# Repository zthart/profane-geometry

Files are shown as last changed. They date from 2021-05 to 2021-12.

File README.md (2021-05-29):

# Profane Geometry

I'm making (attempting) a Eurorack Module.

## What is it?

It's gonna be an oscillator builder/mixer based on a digitally-controlled Triangle Core VCO I found in a [research paper](https://www.researchgate.net/figure/Voltage-controlled-triangle-signal-generator-circuit_fig1_276412272).
It will be controlled by the atsamd21 or atsamd11 (depending on what I end up needing and what is in stock) family of MCUs and have firmware written in Rust!

## Dang aren't you like a web developer?

Yes.
I've only barely figured out the building blocks of some of this stuff, and my knowledge extends to pretty much exactly what I've built so far.
There are almost certainly issues with it.
The OSHW community is great though and people who publish the source/schematics for their Eurorack modules have been a massive, _massive_ help.

## Dang isn't there like a global parts shortage.

Yes.
It's annoying.

## Dang can I make one of these?

Sure.
Probably it will be bad.

## What's in this repo?

- The `./profane_geometry` directory houses the KiCad project for the oscillator board
- The `./profane_geometry_jackboard` directory houses the KiCad project for the jackboard
- The `./firmare` directory contains some testing firmare designed for the first iteration of the jackboard, which allows for an Adafruit Feather M0 to be attached with breadboard-pitch pin sockets

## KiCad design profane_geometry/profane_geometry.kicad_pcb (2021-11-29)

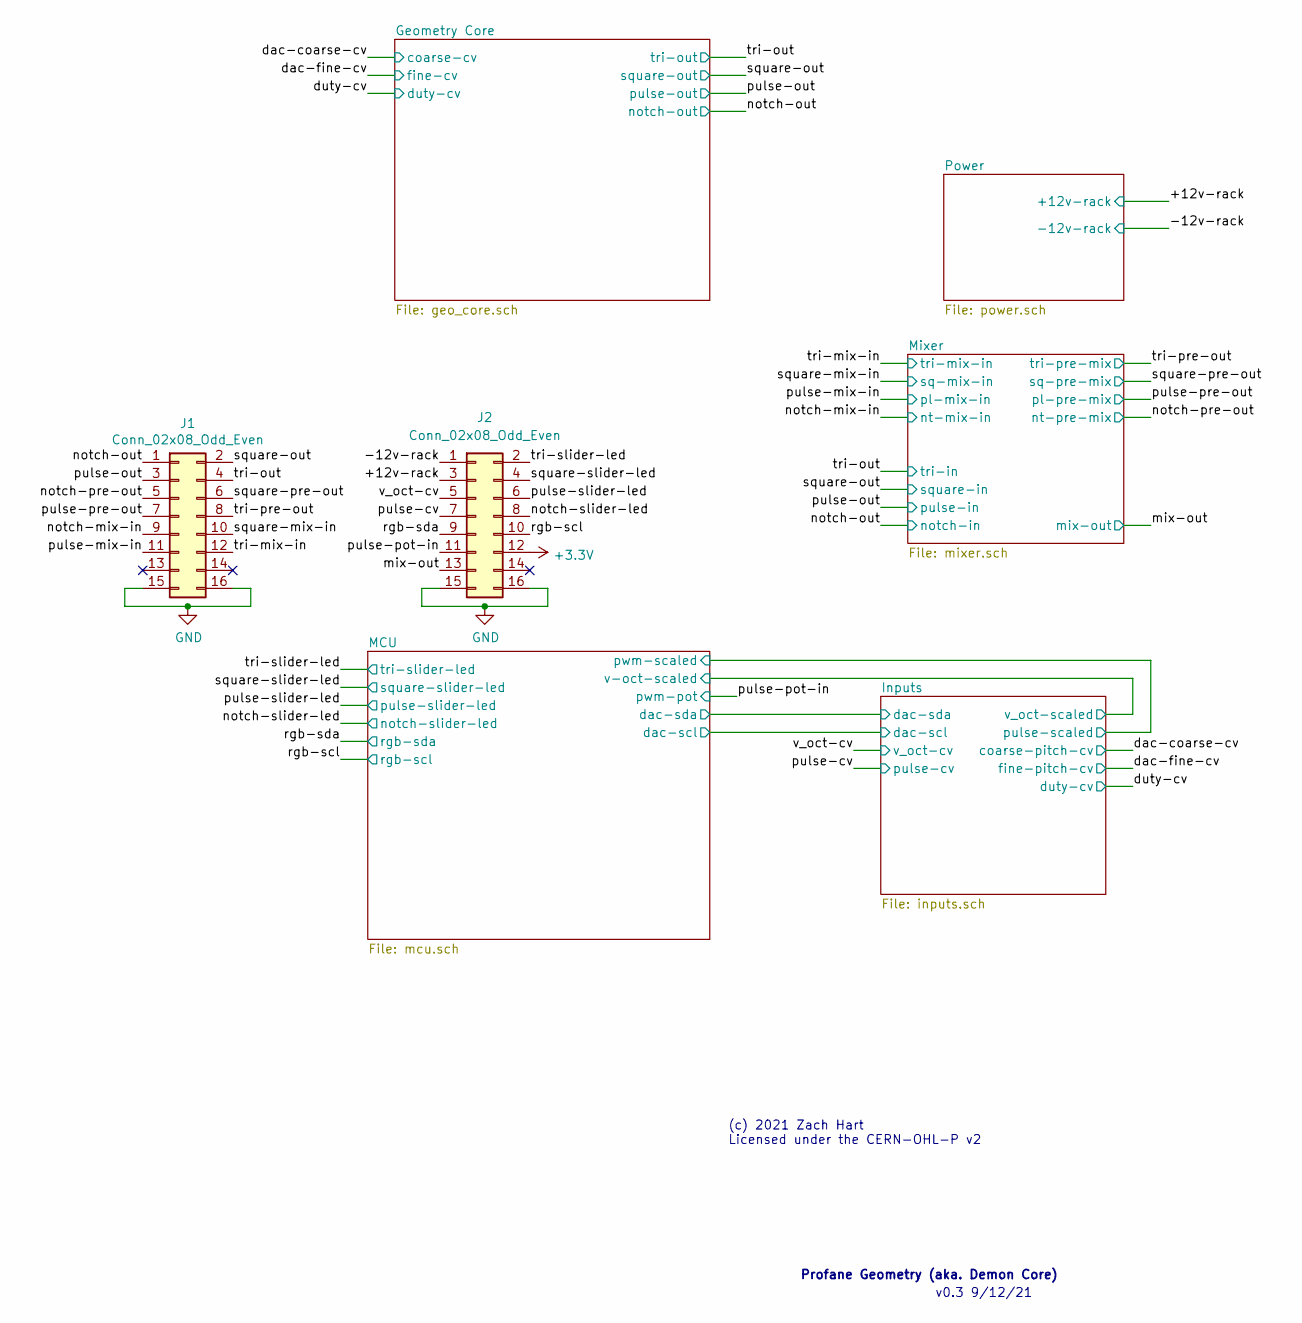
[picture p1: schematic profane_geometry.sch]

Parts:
J1, J2: Conn_02x08_Odd_Even; PinHeader_2x08_P2.54mm_Vertical

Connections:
/+12v-rack: J2.3; also elsewhere on the board
/-12v-rack: J2.1; also elsewhere on the board
/mix-out: J2.13; also elsewhere on the board
/notch-mix-in: J1.9; also elsewhere on the board
/notch-out: J1.1; also elsewhere on the board
/notch-pre-out: J1.5; also elsewhere on the board
/notch-slider-led: J2.8; also elsewhere on the board
/pulse-cv: J2.7; also elsewhere on the board
/pulse-mix-in: J1.11; also elsewhere on the board
/pulse-out: J1.3; also elsewhere on the board
/pulse-pot-in: J2.11; also elsewhere on the board
/pulse-pre-out: J1.7; also elsewhere on the board
/pulse-slider-led: J2.6; also elsewhere on the board
/rgb-scl: J2.10; also elsewhere on the board
/rgb-sda: J2.9; also elsewhere on the board
/square-mix-in: J1.10; also elsewhere on the board
/square-out: J1.2; also elsewhere on the board
/square-pre-out: J1.6; also elsewhere on the board
/square-slider-led: J2.4; also elsewhere on the board
/tri-mix-in: J1.12; also elsewhere on the board
/tri-out: J1.4; also elsewhere on the board
/tri-pre-out: J1.8; also elsewhere on the board
/tri-slider-led: J2.2; also elsewhere on the board
/v_oct-cv: J2.5; also elsewhere on the board
GND: J1.15, J1.16, J2.15, J2.16; also elsewhere on the board

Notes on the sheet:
Profane Geometry (aka. Demon Core)
(c) 2021 Zach Hart Licensed under the CERN-OHL-P v2
v0.3 9/12/21

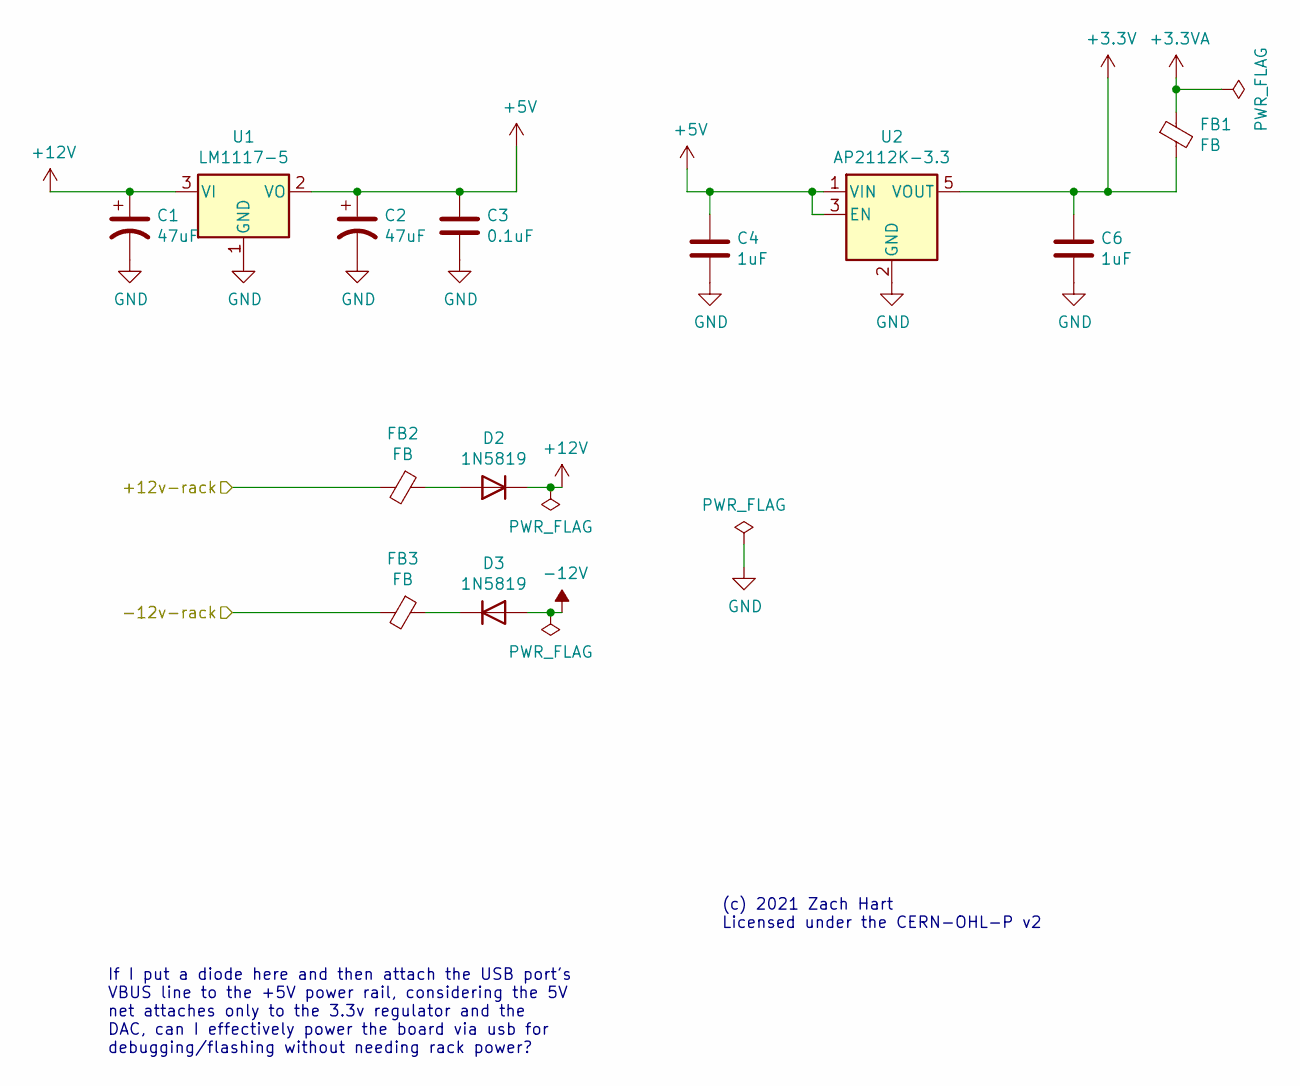
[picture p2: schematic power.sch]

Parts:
C1, C2: 47uF; CP_Elec_6.3x5.7; MFG Part No. 35SVPK47M
C3: 0.1uF; C_0805_2012Metric; MFG Part No. 08055C104KAT4A
C4, C6: 1uF; C_0805_2012Metric; MFG Part No. 0805DC105KAT2A
D2, D3: 1N5819; D_SOD-123; MFG Part No. 1N5819HWQ-7-F
FB1, FB2, FB3: FB; L_1210_3225Metric_Pad1.42x2.65mm_HandSolder; MFG Part No. 742792312
U1: LM1117-5; SOT-223-3_TabPin2; MFG Part No. LM1117MP-5.0/NOPB
U2: AP2112K-3.3; SOT-23-5; MFG Part No. AP2112K-3.3TRG1

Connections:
+3.3VA: FB1.1; also elsewhere on the board
+5V: C2.1, C3.1, C4.1, U1.2 (VO), U2.1 (VIN), U2.3 (EN); also elsewhere on the board
+12V: C1.1, D2.1 (K), U1.3 (VI); also elsewhere on the board
-12V: D3.2 (A); also elsewhere on the board
/+12v-rack: FB2.2; also elsewhere on the board
/-12v-rack: FB3.2; also elsewhere on the board
GND: C1.2, C2.2, C3.2, C4.2, C6.2, U1.1 (GND), U2.2 (GND); also elsewhere on the board
unnamed: D2.2 (A), FB2.1
unnamed: D3.1 (K), FB3.1

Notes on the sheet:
(c) 2021 Zach Hart Licensed under the CERN-OHL-P v2
If I put a diode here and then attach the USB port's VBUS line to the +5V power rail, considering the 5V net attaches only to the 3.3v regulator and the DAC, can I effectively power the board via usb for debugging/flashing without needing rack power?

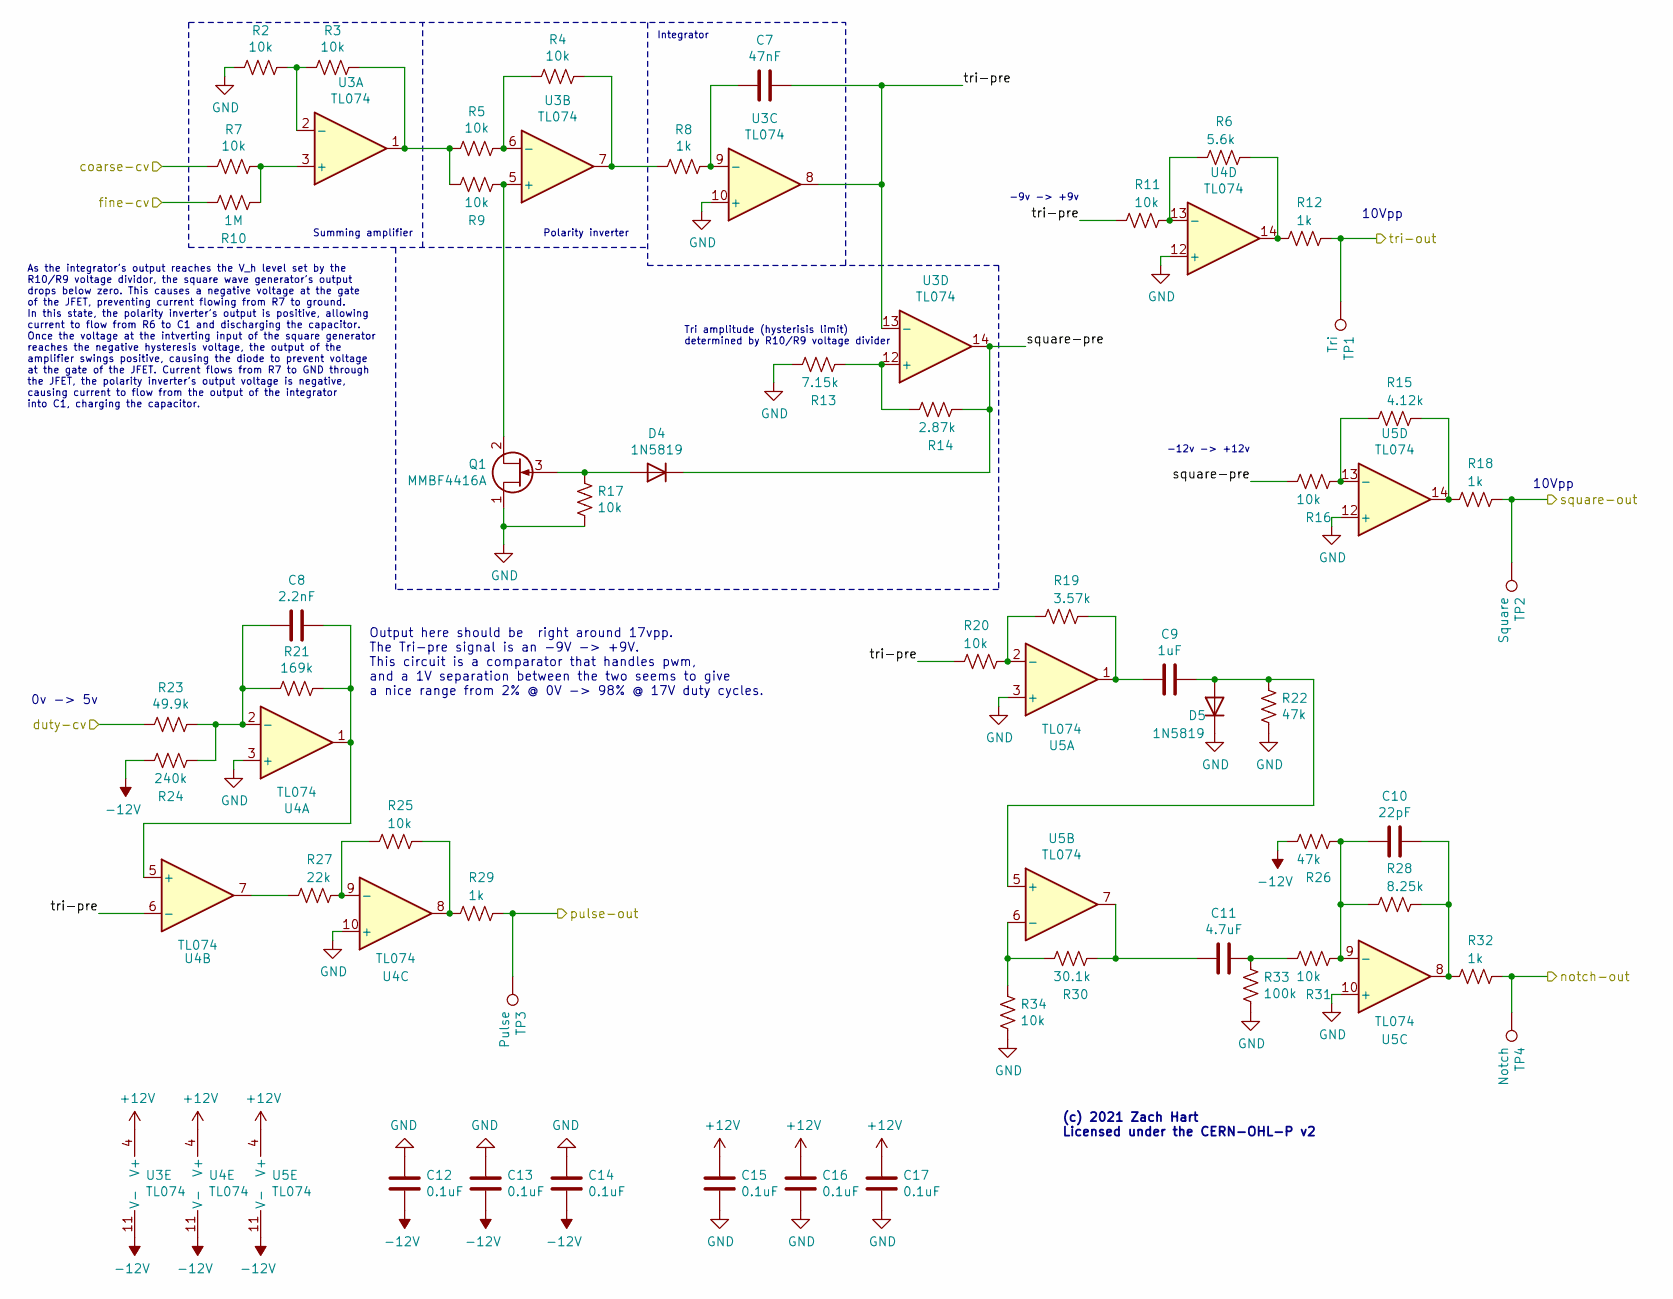
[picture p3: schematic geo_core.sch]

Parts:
C7: 47nF; C_0805_2012Metric; MFG Part No. 08055C473KAT2A
C8: 2.2nF; C_0805_2012Metric; MFG Part No. 08055C222KAT2A
C9: 1uF; C_0805_2012Metric; MFG Part No. 0805DC105KAT2A
C10: 22pF; C_0805_2012Metric; MFG Part No. 08055A220KAT4A
C11: 4.7uF; C_0805_2012Metric; MFG Part No. 08053C475KAT2A
C12, C13, C14, C15, C16, C17: 0.1uF; C_0805_2012Metric; MFG Part No. 08055C104KAT4A
D4, D5: 1N5819; D_SOD-123; MFG Part No. 1N5819HWQ-7-F
Q1: MMBF4416A; SOT-23; MFG Part No. MMBF4416A
R2, R3, R4, R5, R7, R9, R11, R16, R17, R20, R25, R31, R34: 10k; R_0805_2012Metric; MFG Part No. RMCF0805FT10K0
R6: 5.6k; R_0805_2012Metric; MFG Part No. RMCF0805FT5K60
R8, R12, R18, R29, R32: 1k; R_0805_2012Metric; MFG Part No. RMCF0805FT1K00
R10: 1M; R_0805_2012Metric; MFG Part No. RMCF0805FT1M00
R13: 7.15k; R_0805_2012Metric; MFG Part No. RMCF0805FT7K15
R14: 2.87k; R_0805_2012Metric; MFG Part No. RMCF0805FT2K87
R15: 4.12k; R_0805_2012Metric; MFG Part No. RMCF0805FT4K12
R19: 3.57k; R_0805_2012Metric; MFG Part No. RMCF0805FT3K57
R21: 169k; R_0805_2012Metric; MFG Part No. RMCF0805FT169K
R22, R26: 47k; R_0805_2012Metric; MFG Part No. RMCF0805FT47K0
R23: 49.9k; R_0805_2012Metric; MFG Part No. RMCF0805FT49K9
R24: 240k; R_0805_2012Metric; MFG Part No. RMCF0805FT240K
R27: 22k; R_0805_2012Metric; MFG Part No. RMCF0805FT22K0
R28: 8.25k; R_0805_2012Metric; MFG Part No. RMCF0805FT8K25
R30: 30.1k; R_0805_2012Metric; MFG Part No. RMCF0805FT30K1
R33: 100k; R_0805_2012Metric; MFG Part No. RMCF0805FT100K
TP1: Tri; TestPoint_Pad_D1.0mm
TP2: Square; TestPoint_Pad_D1.0mm
TP3: Pulse; TestPoint_Pad_D1.0mm
TP4: Notch; TestPoint_Pad_D1.0mm
U3, U4, U5: TL074; SSOP-14_5.3x6.2mm_P0.65mm; MFG Part No. TL074CDBR

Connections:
+12V: C15.1, C16.1, C17.1, U3.4 (V+), U4.4 (V+), U5.4 (V+); also elsewhere on the board
-12V: C12.2, C13.2, C14.2, R24.2, R26.2, U3.11 (V-), U4.11 (V-), U5.11 (V-); also elsewhere on the board
/Geometry Core/square-pre: D4.1 (K), R14.1, R16.2, U3.14
/Geometry Core/tri-pre: C7.1, R11.2, R20.2, U3.8, U3.13 (-), U4.6 (-)
/dac-coarse-cv: R7.2; also elsewhere on the board
/dac-fine-cv: R10.2; also elsewhere on the board
/duty-cv: R23.2; also elsewhere on the board
/notch-out: R32.1, TP4.1; also elsewhere on the board
/pulse-out: R29.1, TP3.1; also elsewhere on the board
/square-out: R18.1, TP2.1; also elsewhere on the board
/tri-out: R12.1, TP1.1; also elsewhere on the board
GND: C12.1, C13.1, C14.1, C15.2, C16.2, C17.2, D5.1 (K), Q1.1 (D), R2.2, R13.2, R17.1, R22.2, R33.2, R34.2, U3.10 (+), U4.3 (+), U4.10 (+), U4.12 (+), U5.3 (+), U5.10 (+), U5.12 (+); also elsewhere on the board
unnamed: C7.2, R8.1, U3.9 (-)
unnamed: C8.1, R21.1, U4.1, U4.5 (+)
unnamed: C8.2, R21.2, R23.1, R24.1, U4.2 (-)
unnamed: C9.1, D5.2 (A), R22.1, U5.5 (+)
unnamed: C9.2, R19.1, U5.1
unnamed: C10.1, R28.1, R32.2, U5.8
unnamed: C10.2, R26.1, R28.2, R31.1, U5.9 (-)
unnamed: C11.1, R31.2, R33.1
unnamed: C11.2, R30.1, U5.7
unnamed: D4.2 (A), Q1.3 (G), R17.2
unnamed: Q1.2 (S), R9.1, U3.5 (+)
unnamed: R2.1, R3.2, U3.2 (-)
unnamed: R3.1, R5.2, R9.2, U3.1
unnamed: R4.1, R8.2, U3.7
unnamed: R4.2, R5.1, U3.6 (-)
unnamed: R7.1, R10.1, U3.3 (+)
unnamed: R6.2, R11.1, U4.13 (-)
unnamed: R6.1, R12.2, U4.14
unnamed: R13.1, R14.2, U3.12 (+)
unnamed: R15.1, R18.2, U5.14
unnamed: R15.2, R16.1, U5.13 (-)
unnamed: R19.2, R20.1, U5.2 (-)
unnamed: R25.1, R29.2, U4.8
unnamed: R25.2, R27.1, U4.9 (-)
unnamed: R27.2, U4.7
unnamed: R30.2, R34.1, U5.6 (-)

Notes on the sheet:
10Vpp
-12v -> +12v
-9v -> +9v
Tri amplitude (hysterisis limit) determined by R10/R9 voltage divider
Summing amplifier
Polarity inverter
Integrator
As the integrator's output reaches the V_h level set by the R10/R9 voltage dividor, the square wave generator's output drops below zero. This causes a negative voltage at the gate of the JFET, preventing current flowing from R7 to ground. In this state, the polarity inverter's output is positive, a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
0v -> 5v
(c) 2021 Zach Hart Licensed under the CERN-OHL-P v2
Output here should be right around 17vpp. The Tri-pre signal is an -9V -> +9V. This circuit is a comparator that handles pwm, and a 1V separation between the two seems to give a nice range from 2% @ 0V -> 98% @ 17V duty cycles.

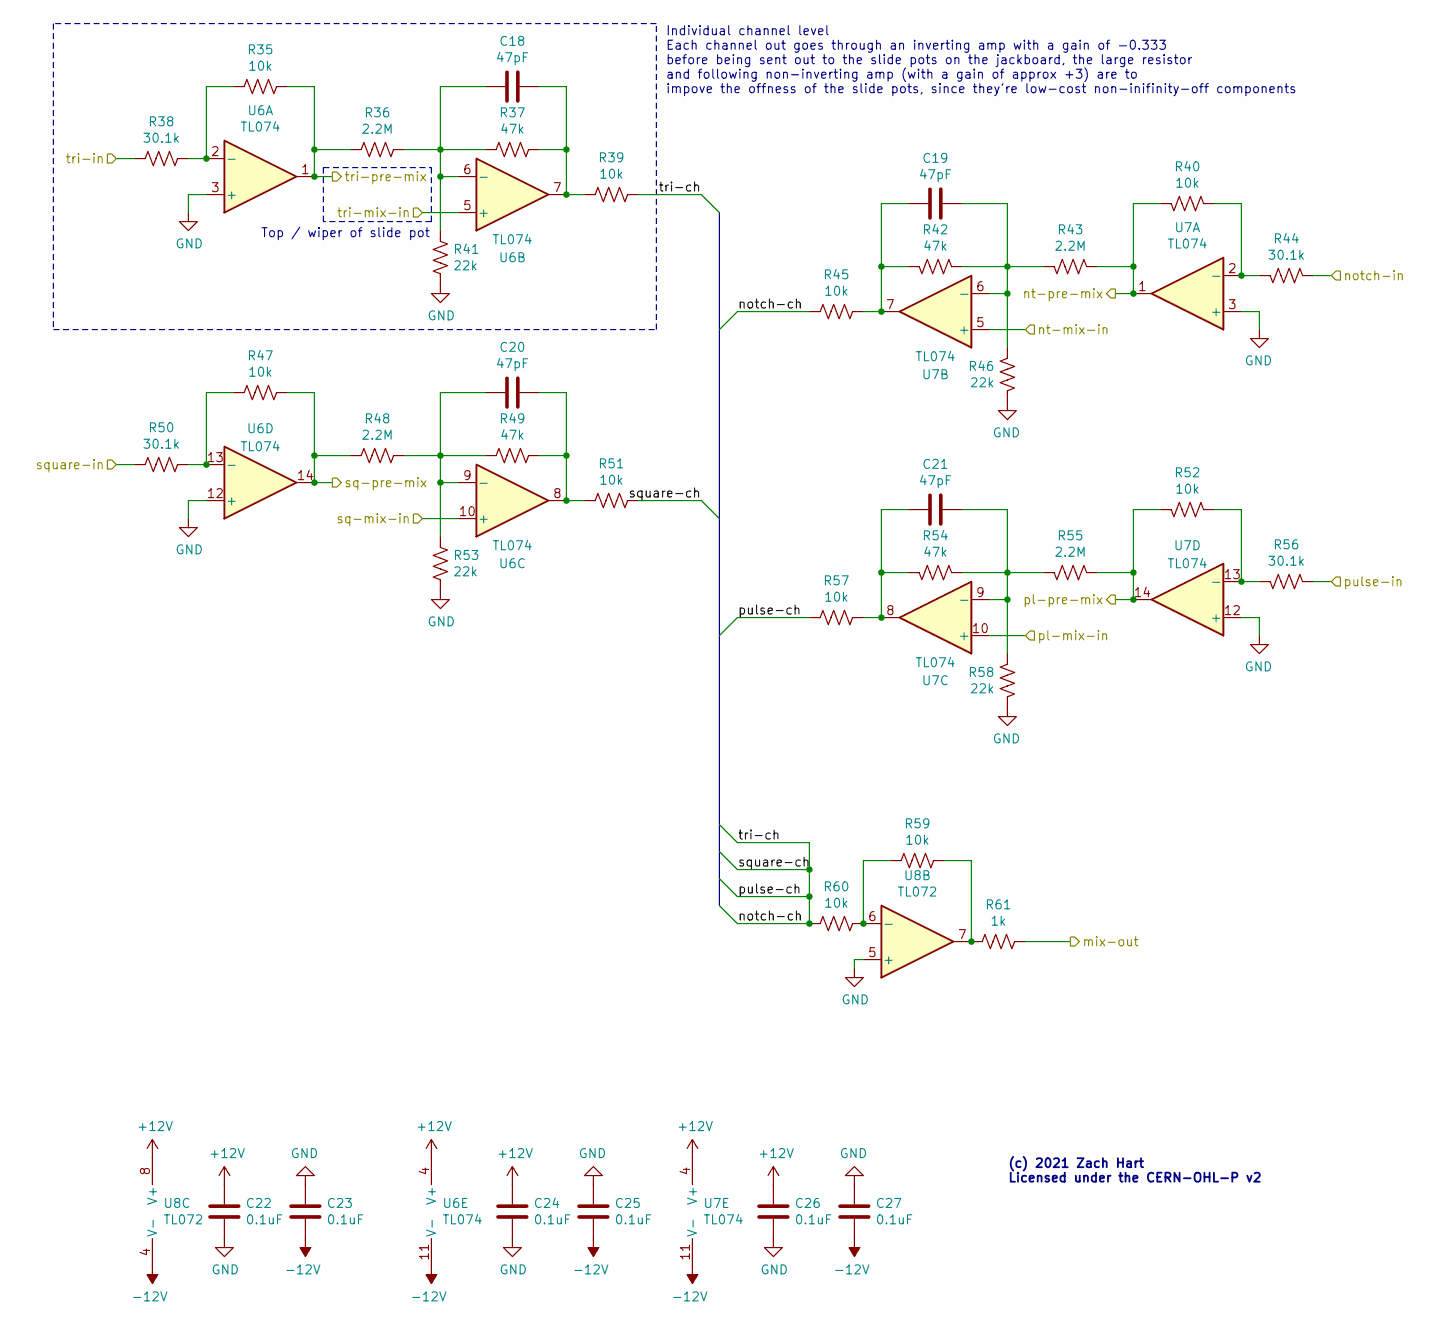
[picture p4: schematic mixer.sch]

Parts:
C18, C19, C20, C21: 47pF; C_0805_2012Metric; MFG Part No. 08055A470KAT4A
C22, C23, C24, C25, C26, C27: 0.1uF; C_0805_2012Metric; MFG Part No. 08055C104KAT4A
R35, R39, R40, R45, R47, R51, R52, R57, R59, R60: 10k; R_0805_2012Metric; MFG Part No. RMCF0805FT10K0
R36, R43, R48, R55: 2.2M; R_0805_2012Metric; MFG Part No. RMCF0805FT2M20
R37, R42, R49, R54: 47k; R_0805_2012Metric; MFG Part No. RMCF0805FT47K0
R38, R44, R50, R56: 30.1k; R_0805_2012Metric; MFG Part No. RMCF0805FT30K1
R41, R46, R53, R58: 22k; R_0805_2012Metric; MFG Part No. RMCF0805FT22K0
R61: 1k; R_0805_2012Metric; MFG Part No. RMCF0805FT1K00
U6, U7: TL074; SSOP-14_5.3x6.2mm_P0.65mm; MFG Part No. TL074CDBR
U8: TL072; SOIC-8_3.9x4.9mm_P1.27mm; MFG Part No. TL072QDREP

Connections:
+12V: C22.1, C24.1, C26.1, U6.4 (V+), U7.4 (V+), U8.8 (V+); also elsewhere on the board
-12V: C23.2, C25.2, C27.2, U6.11 (V-), U7.11 (V-), U8.4 (V-); also elsewhere on the board
/Mixer/notch-ch: R39.1, R45.2, R51.1, R57.2, R60.2
/mix-out: R61.1; also elsewhere on the board
/notch-mix-in: U7.5 (+); also elsewhere on the board
/notch-out: R44.2; also elsewhere on the board
/notch-pre-out: R40.1, R43.2, U7.1; also elsewhere on the board
/pulse-mix-in: U7.10 (+); also elsewhere on the board
/pulse-out: R56.2; also elsewhere on the board
/pulse-pre-out: R52.1, R55.2, U7.14; also elsewhere on the board
/square-mix-in: U6.10 (+); also elsewhere on the board
/square-out: R50.2; also elsewhere on the board
/square-pre-out: R47.1, R48.2, U6.14; also elsewhere on the board
/tri-mix-in: U6.5 (+); also elsewhere on the board
/tri-out: R38.2; also elsewhere on the board
/tri-pre-out: R35.1, R36.2, U6.1; also elsewhere on the board
GND: C22.2, C23.1, C24.2, C25.1, C26.2, C27.1, R41.1, R46.1, R53.1, R58.1, U6.3 (+), U6.12 (+), U7.3 (+), U7.12 (+), U8.5 (+); also elsewhere on the board
unnamed: C18.1, R37.1, R39.2, U6.7
unnamed: C18.2, R36.1, R37.2, R41.2, U6.6 (-)
unnamed: C19.1, R42.1, R45.1, U7.7
unnamed: C19.2, R42.2, R43.1, R46.2, U7.6 (-)
unnamed: C20.1, R49.1, R51.2, U6.8
unnamed: C20.2, R48.1, R49.2, R53.2, U6.9 (-)
unnamed: C21.1, R54.1, R57.1, U7.8
unnamed: C21.2, R54.2, R55.1, R58.2, U7.9 (-)
unnamed: R35.2, R38.1, U6.2 (-)
unnamed: R40.2, R44.1, U7.2 (-)
unnamed: R47.2, R50.1, U6.13 (-)
unnamed: R52.2, R56.1, U7.13 (-)
unnamed: R59.1, R61.2, U8.7
unnamed: R59.2, R60.1, U8.6 (-)

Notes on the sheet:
(c) 2021 Zach Hart Licensed under the CERN-OHL-P v2
Individual channel level Each channel out goes through an inverting amp with a gain of -0.333 before being sent out to the slide pots on the jackboard, the large resistor and following non-inverting amp (with a gain of approx +3) are to impove the offness of the slide pots, since they're low-cost n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
Top / wiper of slide pot

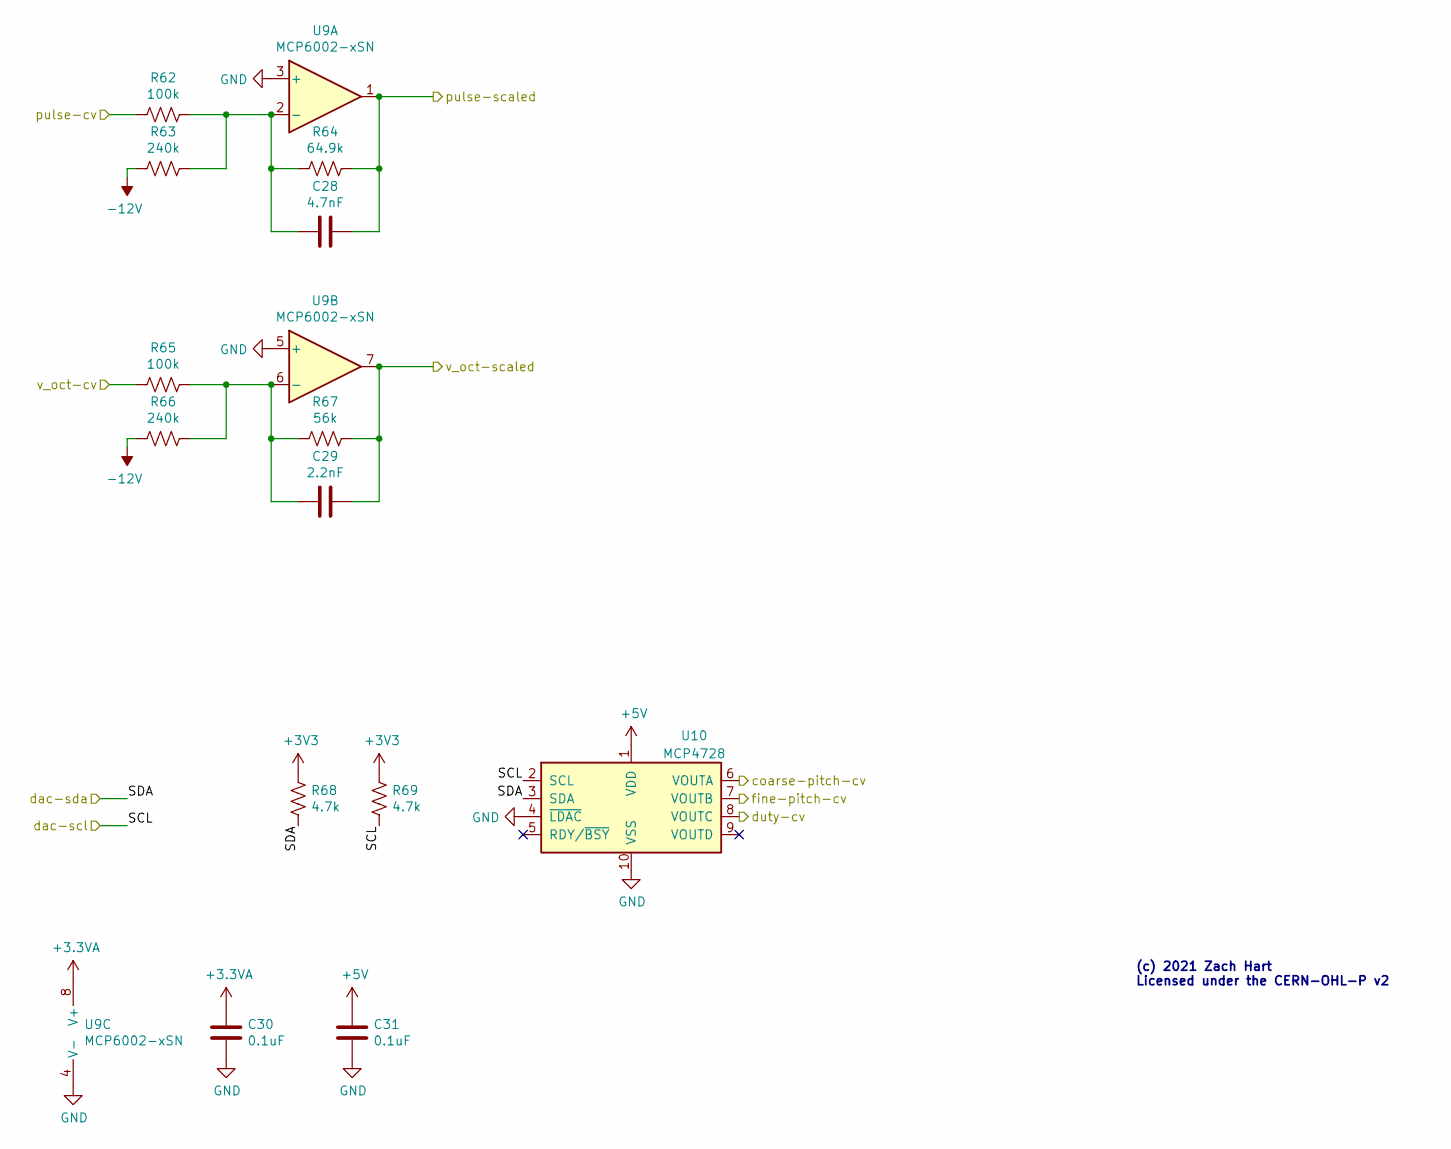
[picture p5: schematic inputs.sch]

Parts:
C28: 4.7nF; C_0805_2012Metric; MFG Part No. 08055C472KAT2A
C29: 2.2nF; C_0805_2012Metric; MFG Part No. 08055C222KAT2A
C30, C31: 0.1uF; C_0805_2012Metric; MFG Part No. 08055C104KAT4A
R62, R65: 100k; R_0805_2012Metric; MFG Part No. RMCF0805FT100K
R63, R66: 240k; R_0805_2012Metric; MFG Part No. RMCF0805FT240K
R64: 64.9k; R_0805_2012Metric; MFG Part No. RMCF0805FT64K9
R67: 56k; R_0805_2012Metric; MFG Part No. RMCF0805FT56K0
R68, R69: 4.7k; R_0805_2012Metric; MFG Part No. RMCF0805FT4K70
U9: MCP6002-xSN; SOIC-8_3.9x4.9mm_P1.27mm; MFG Part No. MCP6002-I/SN
U10: MCP4728; MSOP-10_3x3mm_P0.5mm; MFG Part No. MCP4728-E/UN

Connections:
+3.3VA: C30.2, U9.8 (V+); also elsewhere on the board
+5V: C31.2, U10.1 (VDD); also elsewhere on the board
-12V: R63.1, R66.1; also elsewhere on the board
/Inputs/dac-scl: R69.2, U10.2 (SCL); also elsewhere on the board
/Inputs/dac-sda: R68.2, U10.3 (SDA); also elsewhere on the board
/Inputs/pulse-scaled: C28.1, R64.2, U9.1; also elsewhere on the board
/MCU/v-oct-scaled: C29.1, R67.2, U9.7; also elsewhere on the board
/dac-coarse-cv: U10.6 (VOUTA); also elsewhere on the board
/dac-fine-cv: U10.7 (VOUTB); also elsewhere on the board
/duty-cv: U10.8 (VOUTC); also elsewhere on the board
/pulse-cv: R62.2; also elsewhere on the board
/v_oct-cv: R65.2; also elsewhere on the board
GND: C30.1, C31.1, U9.3 (+), U9.4 (V-), U9.5 (+), U10.4 (~LDAC), U10.10 (VSS); also elsewhere on the board
unnamed: C28.2, R62.1, R63.2, R64.1, U9.2 (-)
unnamed: C29.2, R65.1, R66.2, R67.1, U9.6 (-)

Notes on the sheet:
(c) 2021 Zach Hart Licensed under the CERN-OHL-P v2

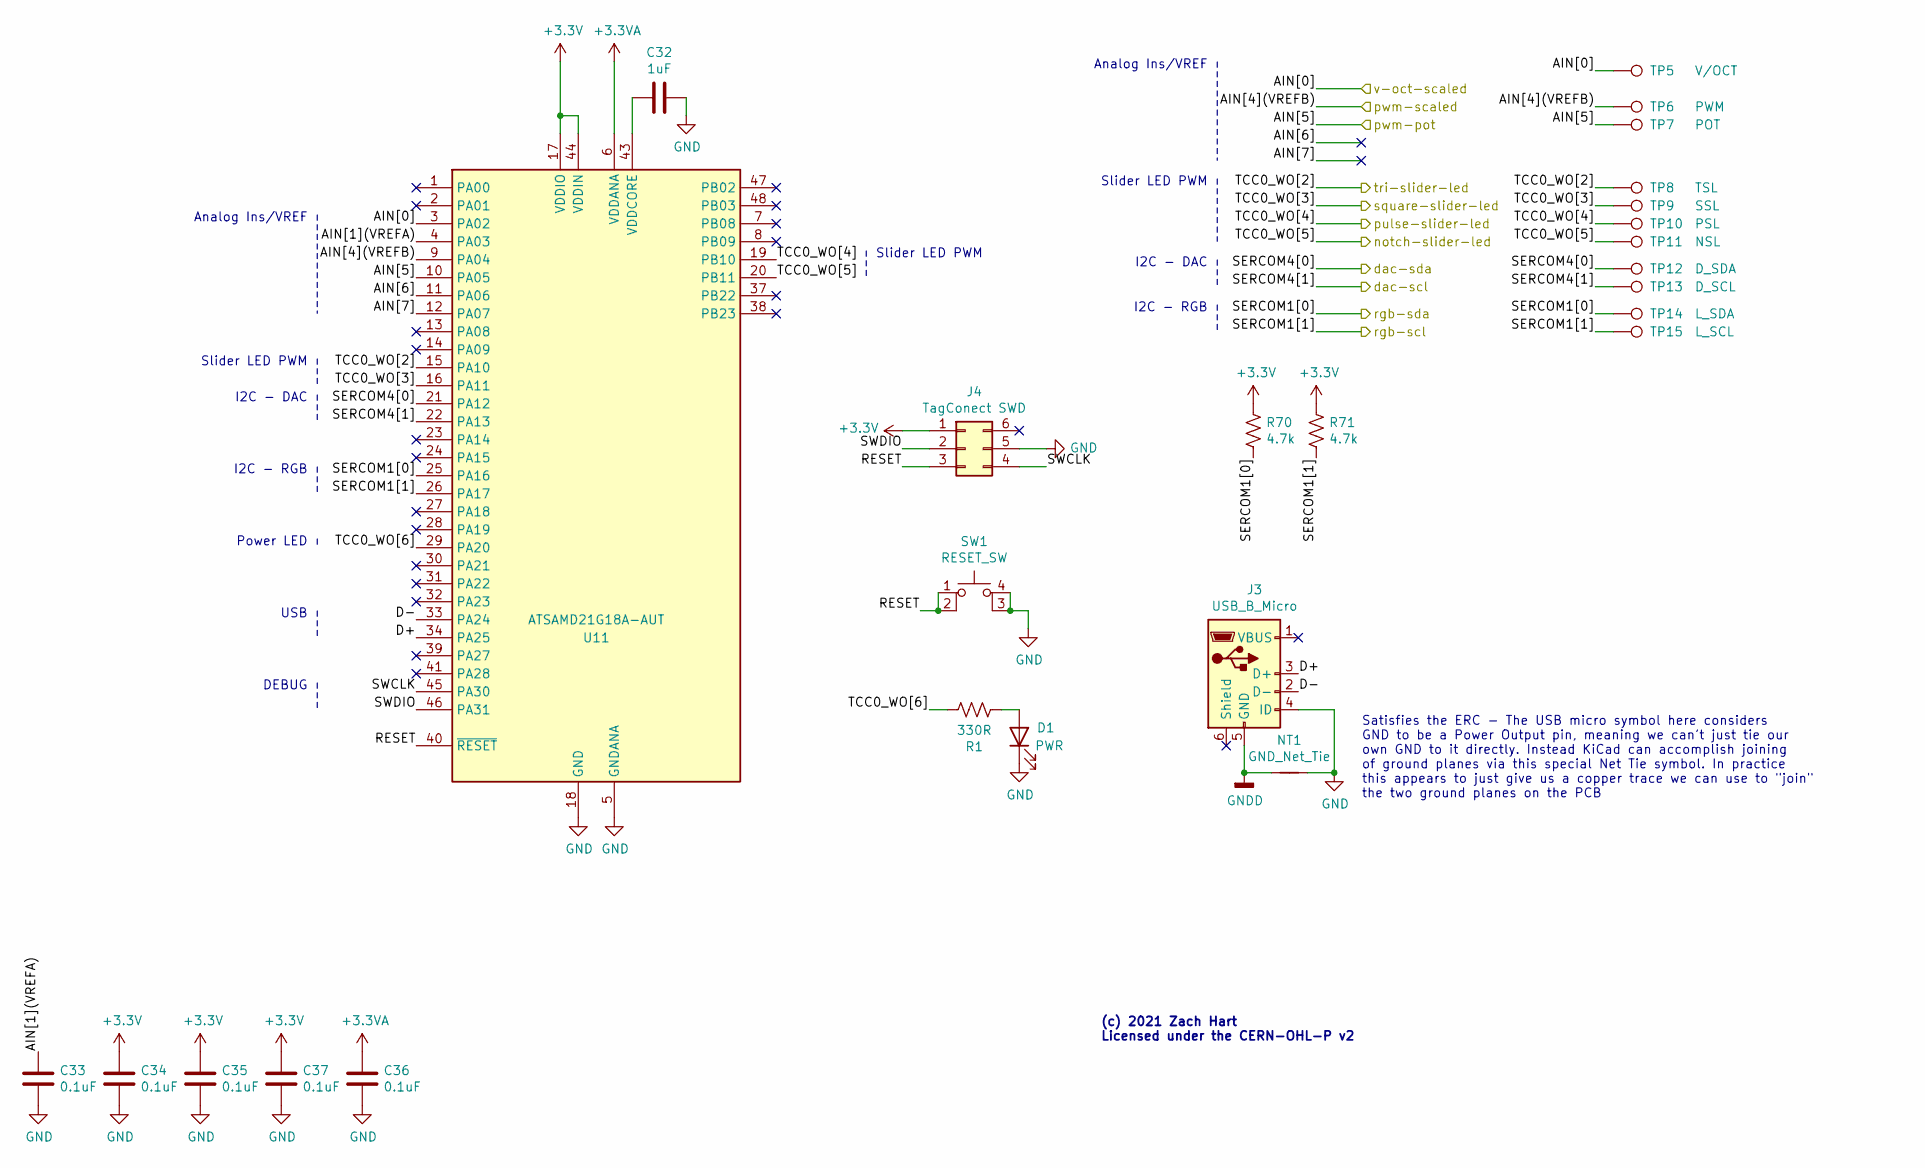
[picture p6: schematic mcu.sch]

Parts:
C32: 1uF; C_0805_2012Metric; MFG Part No. 0805DC105KAT2A
C33, C34, C35, C36, C37: 0.1uF; C_0805_2012Metric; MFG Part No. 08055C104KAT4A
D1: PWR; SunLED-Rev-2-PLCC-SeeThru; MFG Part No. ‎XZMDK45WT-9‎
J3: USB_B_Micro; USB_Micro-B_Amphenol_10103594-0001LF_Horizontal; MFG Part No. 10103594-0001LF
J4: TagConect SWD; Tag-Connect_TC2030-IDC-NL_2x03_P1.27mm_Vertical
NT1: GND_Net_Tie; NetTie-2_SMD_Pad0.5mm
R1: 330R; R_0805_2012Metric; MFG Part No. RMCF0805FT330R
R70, R71: 4.7k; R_0805_2012Metric
SW1: RESET_SW; SPST_TL3365AF180QG_SMD; MFG Part No. TL3365AF180QG
TP5: V/OCT; TestPoint_Pad_D1.0mm
TP6: PWM; TestPoint_Pad_D1.0mm
TP7: POT; TestPoint_Pad_D1.0mm
TP8: TSL; TestPoint_Pad_D1.0mm
TP9: SSL; TestPoint_Pad_D1.0mm
TP10: PSL; TestPoint_Pad_D1.0mm
TP11: NSL; TestPoint_Pad_D1.0mm
TP12: D_SDA; TestPoint_Pad_D1.0mm
TP13: D_SCL; TestPoint_Pad_D1.0mm
TP14: L_SDA; TestPoint_Pad_D1.0mm
TP15: L_SCL; TestPoint_Pad_D1.0mm
U11: ATSAMD21G18A-AUT; TQFP-48_7x7mm_P0.5mm; MFG Part No. ATSAMD21G18A-AUT

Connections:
+3.3VA: C36.2, U11.6 (VDDANA); also elsewhere on the board
/Inputs/dac-scl: TP13.1, U11.22 (PA13); also elsewhere on the board
/Inputs/dac-sda: TP12.1, U11.21 (PA12); also elsewhere on the board
/Inputs/pulse-scaled: TP6.1, U11.9 (PA04); also elsewhere on the board
/MCU/AIN[1](VREFA): C33.2, U11.4 (PA03)
/MCU/AIN[6]: U11.11 (PA06)
/MCU/AIN[7]: U11.12 (PA07)
/MCU/D+: J3.3 (D+), U11.34 (PA25)
/MCU/D-: J3.2 (D-), U11.33 (PA24)
/MCU/RESET: J4.3, SW1.1, SW1.2, U11.40 (~RESET)
/MCU/SWCLK: J4.4, U11.45 (PA30)
/MCU/SWDIO: J4.2, U11.46 (PA31)
/MCU/TCC0_WO[6]: R1.1, U11.29 (PA20)
/MCU/v-oct-scaled: TP5.1, U11.3 (PA02); also elsewhere on the board
/notch-slider-led: TP11.1, U11.20 (PB11); also elsewhere on the board
/pulse-pot-in: TP7.1, U11.10 (PA05); also elsewhere on the board
/pulse-slider-led: TP10.1, U11.19 (PB10); also elsewhere on the board
/rgb-scl: R71.1, TP15.1, U11.26 (PA17); also elsewhere on the board
/rgb-sda: R70.1, TP14.1, U11.25 (PA16); also elsewhere on the board
/square-slider-led: TP9.1, U11.16 (PA11); also elsewhere on the board
/tri-slider-led: TP8.1, U11.15 (PA10); also elsewhere on the board
GND: C32.1, C33.1, C34.1, C35.1, C36.1, C37.1, D1.1 (K), J3.4 (ID), J4.5, NT1.2, SW1.3 (K), SW1.4 (A), U11.5 (GNDANA), U11.18 (GND), U11.35 (GND), U11.42 (GND); also elsewhere on the board
GNDD: J3.5 (GND), NT1.1
unnamed: C32.2, U11.43 (VDDCORE)
unnamed: D1.2 (A), R1.2

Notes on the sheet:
(c) 2021 Zach Hart Licensed under the CERN-OHL-P v2
Analog Ins/VREF
Slider LED PWM
I2C - DAC
USB
DEBUG
I2C - RGB
Power LED
Satisfies the ERC - The USB micro symbol here considers GND to be a Power Output pin, meaning we can't just tie our own GND to it directly. Instead KiCad can accomplish joining of ground planes via this special Net Tie symbol. In practice this appears to just give us a copper trace we can use to "j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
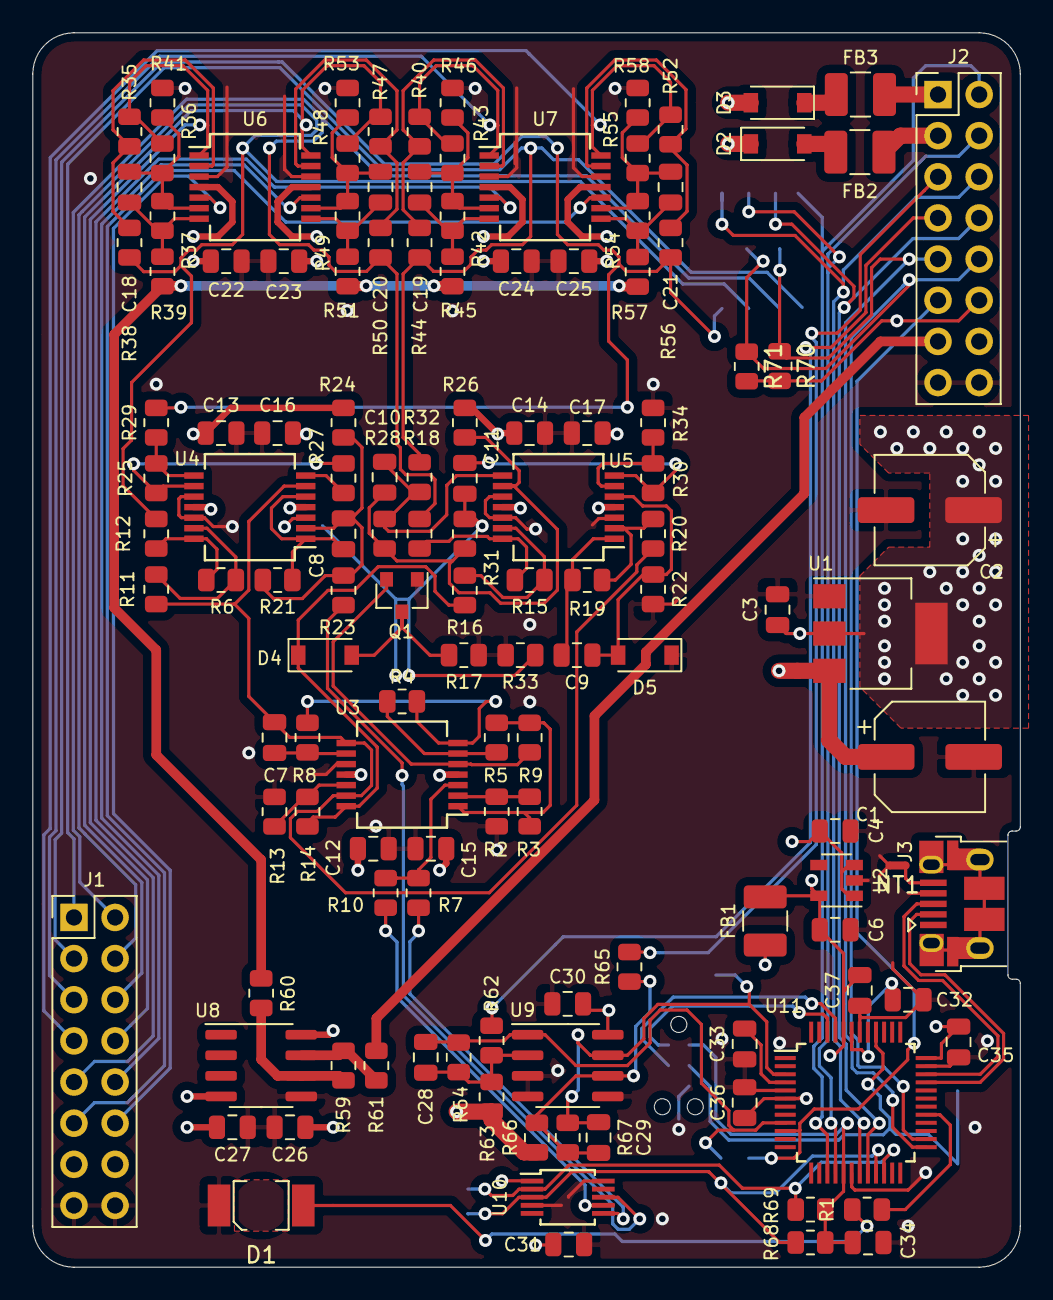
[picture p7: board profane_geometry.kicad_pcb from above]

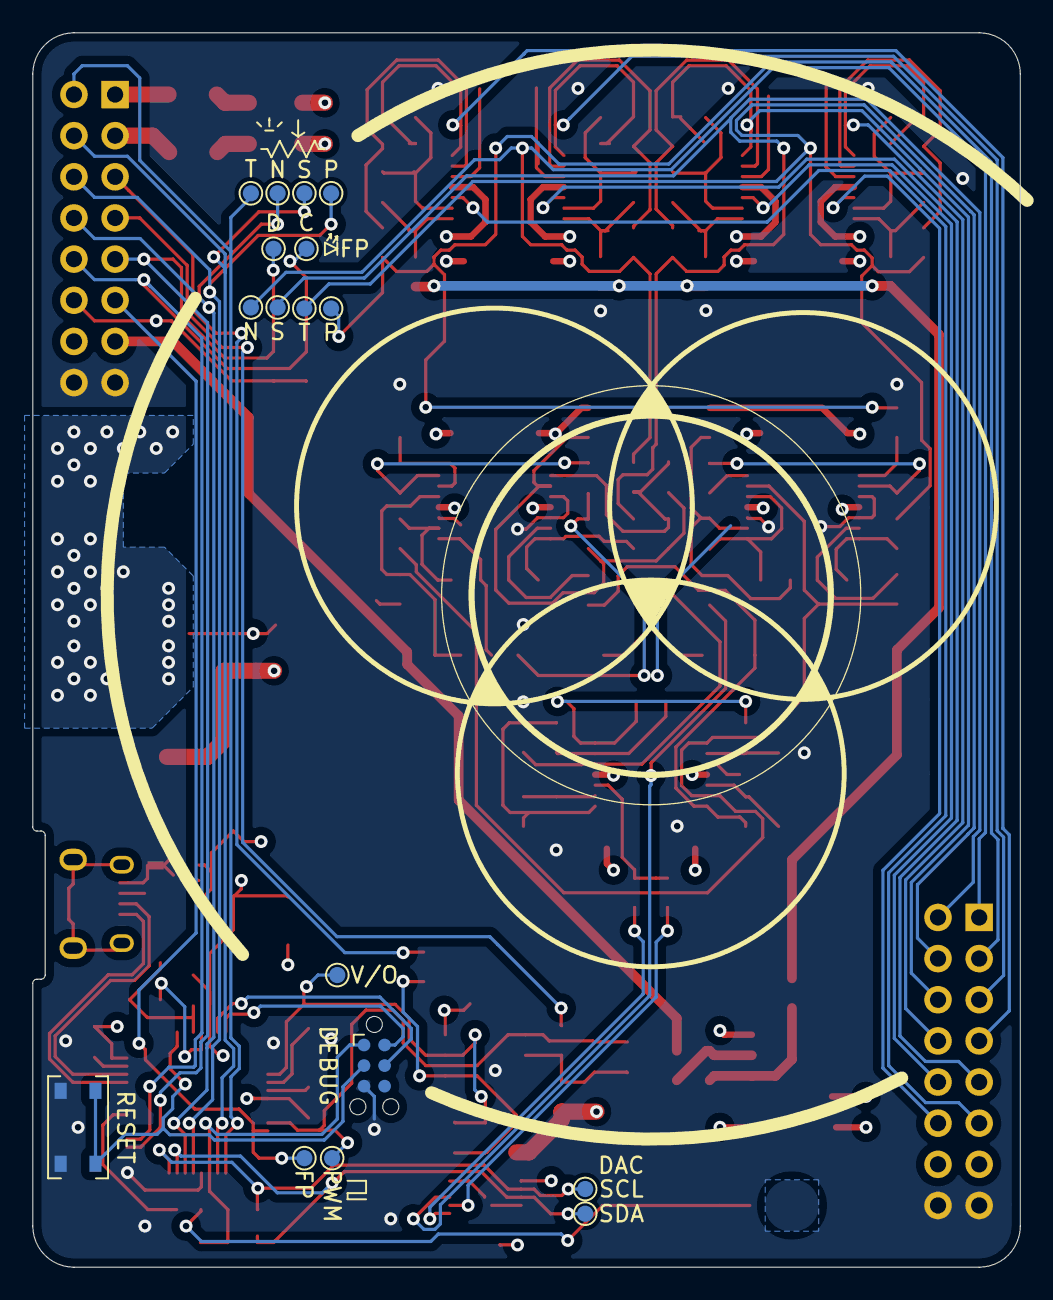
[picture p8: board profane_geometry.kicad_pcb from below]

Board: 4 copper layers, 61.0 x 76.2 mm, 148 parts (17 on the bottom side), 94 nets.

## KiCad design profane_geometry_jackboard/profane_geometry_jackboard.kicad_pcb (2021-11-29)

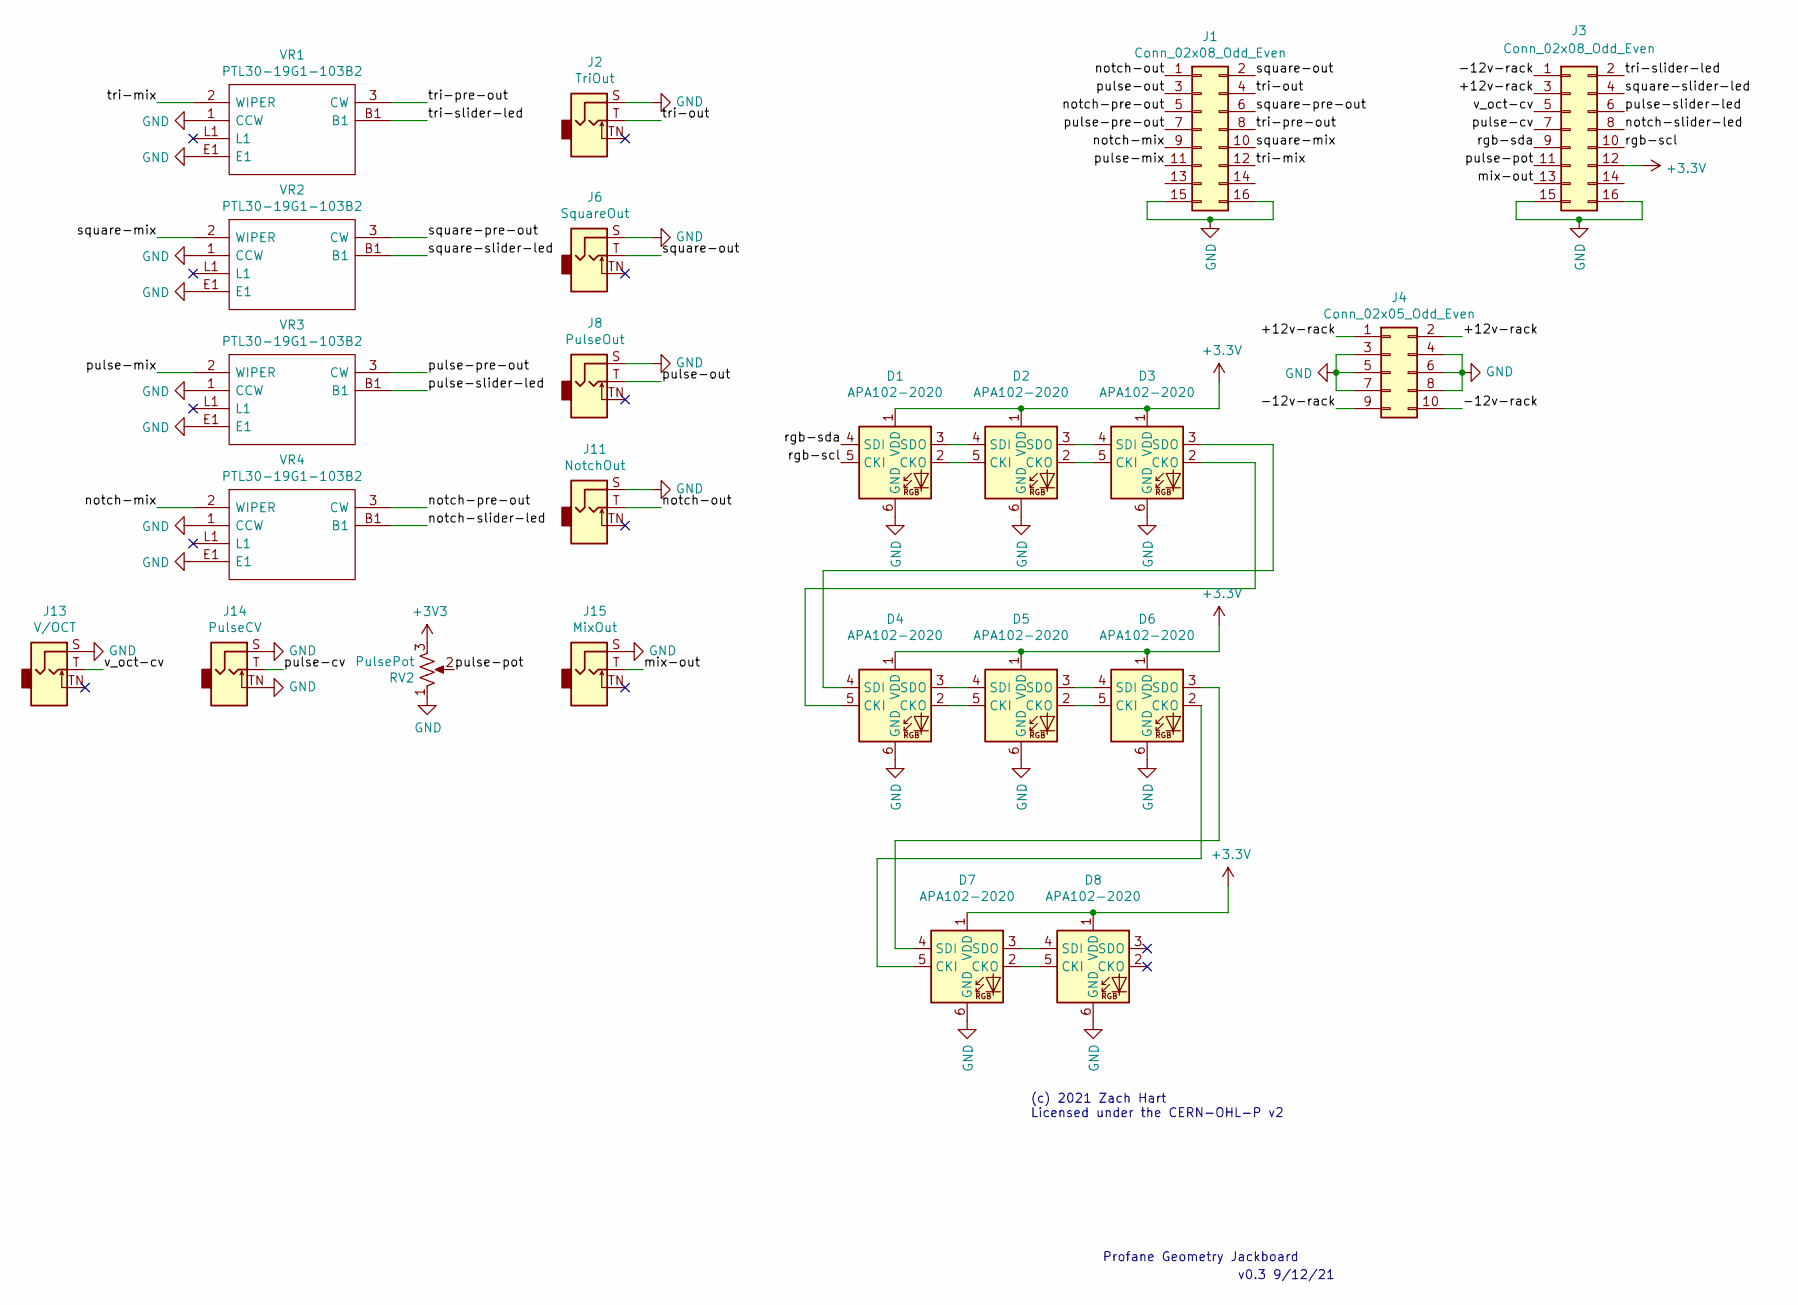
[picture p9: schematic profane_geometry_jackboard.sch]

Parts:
D1, D2, D3, D4, D5, D6, D7, D8: APA102-2020; LED-APA102-2020
J1, J3: Conn_02x08_Odd_Even; PinSocket_2x08_P2.54mm_Vertical
J2: TriOut; Jack_3.5mm_QingPu_WQP-PJ301BM_Vertical
J4: Conn_02x05_Odd_Even; PinHeader_2x05_P2.54mm_Vertical
J6: SquareOut; Jack_3.5mm_QingPu_WQP-PJ301BM_Vertical
J8: PulseOut; Jack_3.5mm_QingPu_WQP-PJ301BM_Vertical
J11: NotchOut; Jack_3.5mm_QingPu_WQP-PJ301BM_Vertical
J13: V/OCT; Jack_3.5mm_QingPu_WQP-PJ301BM_Vertical
J14: PulseCV; Jack_3.5mm_QingPu_WQP-PJ301BM_Vertical
J15: MixOut; Jack_3.5mm_QingPu_WQP-PJ301BM_Vertical
RV2: PulsePot; Potentiometer_TT_P0915N
VR1, VR2, VR3, VR4: PTL30-19G1-103B2; Slider_Potentiometer_Bourns_PTL_30mm; Mouser Part Number 652-PTL30-19G1-103B2

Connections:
/+12v-rack: J3.3, J4.1, J4.2
/-12v-rack: J3.1, J4.9, J4.10
/mix-out: J3.13, J15.T
/notch-mix: J1.9, VR4.2 (WIPER)
/notch-out: J1.1, J11.T
/notch-pre-out: J1.5, VR4.3 (CW)
/notch-slider-led: J3.8, VR4.B1
/pulse-cv: J3.7, J14.T
/pulse-mix: J1.11, VR3.2 (WIPER)
/pulse-out: J1.3, J8.T
/pulse-pot: J3.11, RV2.2
/pulse-pre-out: J1.7, VR3.3 (CW)
/pulse-slider-led: J3.6, VR3.B1
/rgb-scl: D1.5 (CKI), J3.10
/rgb-sda: D1.4 (SDI), J3.9
/square-mix: J1.10, VR2.2 (WIPER)
/square-out: J1.2, J6.T
/square-pre-out: J1.6, VR2.3 (CW)
/square-slider-led: J3.4, VR2.B1
/tri-mix: J1.12, VR1.2 (WIPER)
/tri-out: J1.4, J2.T
/tri-pre-out: J1.8, VR1.3 (CW)
/tri-slider-led: J3.2, VR1.B1
/v_oct-cv: J3.5, J13.T
GND: D1.6 (GND), D2.6 (GND), D3.6 (GND), D4.6 (GND), D5.6 (GND), D6.6 (GND), D7.6 (GND), D8.6 (GND), J1.15, J1.16, J2.S, J3.15, J3.16, J4.3, J4.4, J4.5, J4.6, J4.7, J4.8, J6.S, J8.S, J11.S, J13.S, J14.S, J14.TN, J15.S, RV2.1, VR1.1 (CCW), VR1.E1, VR2.1 (CCW), VR2.E1, VR3.1 (CCW), VR3.E1, VR4.1 (CCW), VR4.E1
unnamed: D1.2 (CKO), D2.5 (CKI)
unnamed: D1.3 (SDO), D2.4 (SDI)
unnamed: D2.2 (CKO), D3.5 (CKI)
unnamed: D2.3 (SDO), D3.4 (SDI)
unnamed: D3.2 (CKO), D4.5 (CKI)
unnamed: D3.3 (SDO), D4.4 (SDI)
unnamed: D4.2 (CKO), D5.5 (CKI)
unnamed: D4.3 (SDO), D5.4 (SDI)
unnamed: D5.2 (CKO), D6.5 (CKI)
unnamed: D5.3 (SDO), D6.4 (SDI)
unnamed: D6.2 (CKO), D7.5 (CKI)
unnamed: D6.3 (SDO), D7.4 (SDI)
unnamed: D7.2 (CKO), D8.5 (CKI)
unnamed: D7.3 (SDO), D8.4 (SDI)

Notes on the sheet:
Profane Geometry Jackboard
(c) 2021 Zach Hart Licensed under the CERN-OHL-P v2
v0.3 9/12/21

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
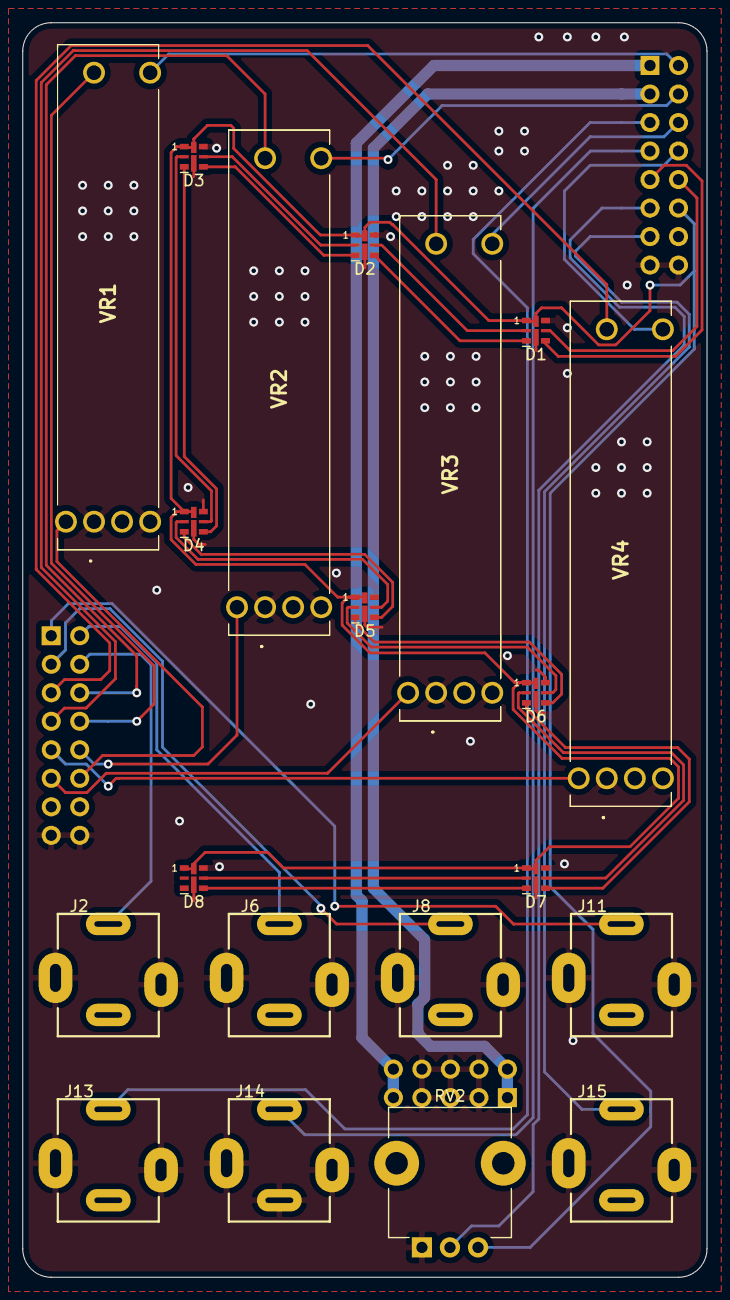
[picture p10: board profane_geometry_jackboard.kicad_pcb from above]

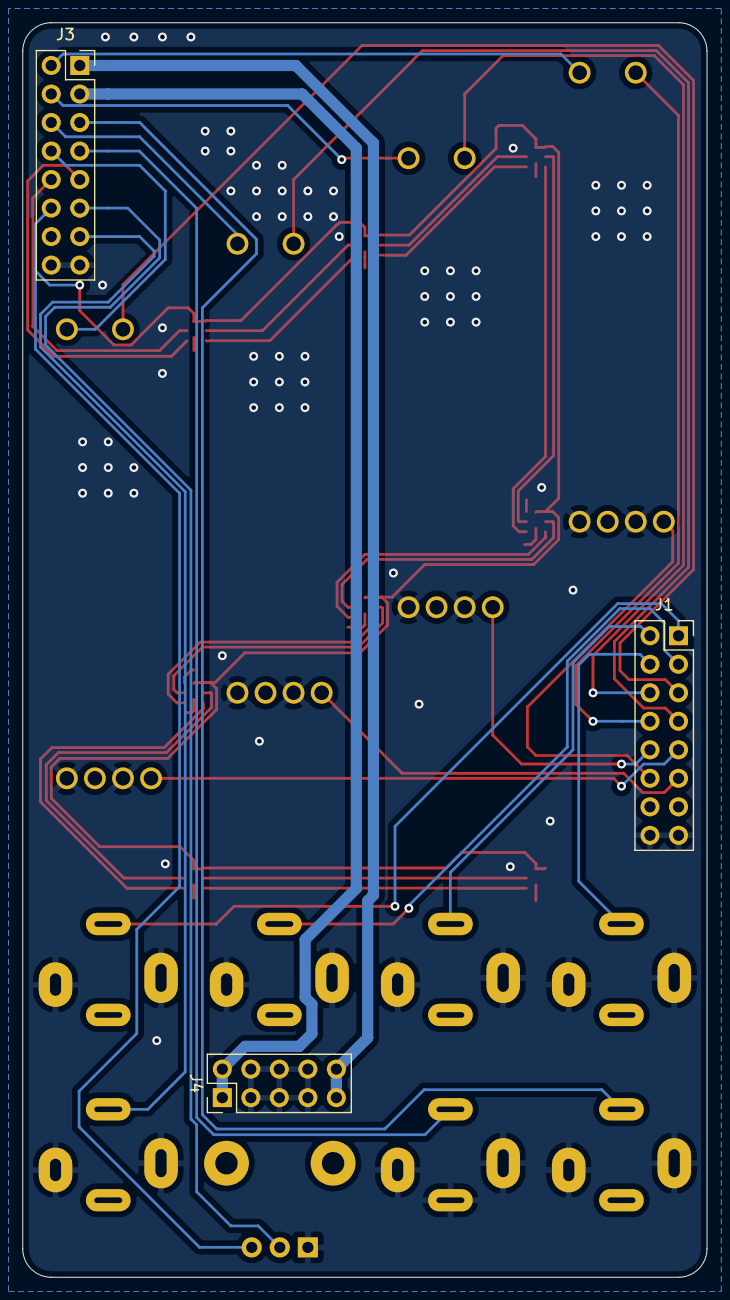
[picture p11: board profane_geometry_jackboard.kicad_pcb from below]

Board: 2 copper layers, 61.0 x 111.8 mm, 23 parts (3 on the bottom side), 40 nets.

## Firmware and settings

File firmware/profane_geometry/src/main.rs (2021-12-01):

#![no_std]
#![no_main]

#[cfg(not(feature = "use_semihosting"))]
use panic_halt as _;
#[cfg(feature = "use_semihosting")]
use panic_semihosting as _;

use bsp::hal;
use bsp::pac;
use profane_geometry_bsp as bsp;

use bsp::entry;

use hal::clock::GenericClockController;
use hal::prelude::*;
use hal::pwm::{Channel, Pwm1, Pwm2};
use hal::sercom::I2CMaster4;
use hal::time::KiloHertz;

use pac::{interrupt, CorePeripherals, Peripherals};

use core::cell::{Cell, RefCell};

use cortex_m::interrupt::Mutex;

use micromath::F32Ext;

mod hw;
mod mcu;

const TOTAL_INS: usize = 3;

static ADC_INSTANCE: Mutex<RefCell<Option<mcu::adc::Adc<pac::ADC>>>> =
    Mutex::new(RefCell::new(None));
static ADC_CHANNELS: Mutex<RefCell<Option<[u8; TOTAL_INS]>>> = Mutex::new(RefCell::new(None));
static ADC_RESULTS: Mutex<RefCell<[u16; TOTAL_INS]>> = Mutex::new(RefCell::new([0; TOTAL_INS]));
static IN_CTR: Mutex<Cell<u8>> = Mutex::new(Cell::new(0));

// A nice little convenience here lets us ignore both the full pin name (e.g. PA11, PB10, etc.)
// _and_ the exact pin configuration (into_alternate::<A>() or into_push_pull_output()).
// Within our BSP we can set these aliases for specific pins in specific modes, and then coerce things into()
// the appropriate type nicely.
//
// If we want to use pwm here, we could use bsp::NtSliderLedPwm instead.
static INT_LED: Mutex<RefCell<Option<bsp::NtSliderLed>>> = Mutex::new(RefCell::new(None));

static POWER_LED: Mutex<RefCell<Option<bsp::PowerLed>>> = Mutex::new(RefCell::new(None));

static DAC_ADDRESS: u8 = 0b01100000;

static PG_INPUTS: Mutex<RefCell<Option<[ProGeoAnalogIn; TOTAL_INS]>>> =
    Mutex::new(RefCell::new(None));

// TODO(zach) - store this struct as inputs, don't reference ADC_RESULTS in main loop, keep critical sections in
// functions within this impl
struct ProGeoAnalogIn {
    /// The zero-indexed number of this input. This represents the index of this input in both the ADC_CHANNELS and
    /// ADC_RESULTS array, so that a given named AnalogIn struct can be used to fetch the current result, rather than
    /// relying on knowing "input x is index 0 is channel _y_ is pin whatever."
    num: usize,

    /// The result of the `channel()` associated func of the Channel trait provided by embedded_hal.
    ///
    /// Requiring the calling code handle fetching these values is an intentional design choice, due to the really funky
    /// nature of the type erasure provided by the atsamd_hal crate. I'm sure with some more effort I could get around
    /// that with an `AnyPin + Channel` implementation here, but this seems simple enough for the moment
    channel: u8,
}

impl ProGeoAnalogIn {
    /// Retrieve the current result for this input from the RefCell.
    ///
    /// This function enters a critical section.
    fn get_current_result(self) -> u16 {
        cortex_m::interrupt::free(|cs| {
            let results = ADC_RESULTS.borrow(cs).borrow();
            results[self.num].clone()
        })
    }
}

fn pg_create_inputs(mut pins: bsp::Pins) {
    use mcu::adc::Adc;

    let v_oct_: bsp::VOct = pins.v_oct.into(); // v/oct scaled
    let pwm_cv_: bsp::PwmCv = pins.pwm_cv.into(); // pulse scaled
    let pwm_pot_: bsp::PwmPot = pins.pwm_pot.into(); // pulse pot

    cortex_m::interrupt::free(|cs| {
        PG_INPUTS.borrow(cs).replace(Some([
            ProGeoAnalogIn {
                num: 0,
                channel: Adc::get_pin_channel(v_oct_),
            },
            ProGeoAnalogIn {
                num: 1,
                channel: Adc::get_pin_channel(pwm_cv_),
            },
            ProGeoAnalogIn {
                num: 2,
                channel: Adc::get_pin_channel(pwm_pot_),
            },
        ]));
    })
}

#[entry]
fn main() -> ! {
    let mut peripherals = Peripherals::take().unwrap();
    let mut core = CorePeripherals::take().unwrap();

    let mut clocks = GenericClockController::with_internal_32kosc(
        peripherals.GCLK,
        &mut peripherals.PM,
        &mut peripherals.SYSCTRL,
        &mut peripherals.NVMCTRL,
    );
    let gclk0 = clocks.gclk0();
    let pins = bsp::Pins::new(peripherals.PORT);

    // First things first - turn our power LED on. We've definitely got power.
    {
        let mut power_led: bsp::PowerLed = pins.power_led.into();
        power_led.set_high().unwrap();

        // Give up the power LED to anyone that may need it later. Potentially useful for debug/error codes.
        cortex_m::interrupt::free(|cs| {
            POWER_LED.borrow(cs).replace(Some(power_led));
        });
    }

    // Configure i2c
    let mut dac = {
        use hw::mcp4728::MCP4728;

        let i2c_sda: bsp::DacSda = pins.dac_sda.into();
        let i2c_scl: bsp::DacScl = pins.dac_scl.into();

        let i2c = I2CMaster4::new(
            &clocks.sercom4_core(&gclk0).unwrap(),
            KiloHertz(400),
            peripherals.SERCOM4,
            &mut peripherals.PM,
            i2c_sda,
            i2c_scl,
        );

        MCP4728::init(i2c, DAC_ADDRESS)
    };

    {
        let mut notch_led = pins.nt_slider_led.into_push_pull_output();
        notch_led.set_low().unwrap();

        cortex_m::interrupt::free(|cs| {
            INT_LED.borrow(cs).replace(Some(notch_led));
        });
    }

    // Analog ins, all ADC inputs need to be sent to function b
    {
        use mcu::adc::Adc;

        let v_oct_: bsp::VOct = pins.v_oct.into(); // v/oct scaled
        let pwm_cv_: bsp::PwmCv = pins.pwm_cv.into(); // pulse scaled
        let pwm_pot_: bsp::PwmPot = pins.pwm_pot.into(); // pulse pot

        let input_channels: [u8; TOTAL_INS] = [
            Adc::get_pin_channel(v_oct_),
            Adc::get_pin_channel(pwm_cv_),
            Adc::get_pin_channel(pwm_pot_),
        ];

        cortex_m::interrupt::free(|cs| ADC_CHANNELS.borrow(cs).replace(Some(input_channels)));
    }

    {
        use hal::pac::adc::{avgctrl, ctrlb};
        use mcu::adc::Adc;
        use mcu::calibration;

        let adc_linearity = calibration::adc_linearity_cal();
        let adc_bias = calibration::adc_bias_cal();

        let adc_builder = Adc::configure(peripherals.ADC, &mut peripherals.PM, &mut clocks);

        let adc = adc_builder
            .with_calibration(adc_bias, adc_linearity)
            .with_samples(avgctrl::SAMPLENUM_A::_32)
            .with_resolution(ctrlb::RESSEL_A::_16BIT)
            .with_reference_buffer()
            .enable();

        // Give up our adc and put it in the mutex
        cortex_m::interrupt::free(|cs| ADC_INSTANCE.borrow(cs).replace(Some(adc)));
        // Enable interrupts
        cortex_m::interrupt::free(|cs| {
            let idx: usize = IN_CTR.borrow(cs).get().into();
            let channel = ADC_CHANNELS.borrow(cs).borrow().as_ref().unwrap()[idx];
            let adc = ADC_INSTANCE.borrow(cs).borrow();
            // enabled interrupts
            adc.as_ref().unwrap().enable_interrupts(&mut core.NVIC);
            // begin
            adc.as_ref().unwrap().scan_channel(channel);
        });
    }

    let mut pwm1 = {
        let tcc0_tcc1 = &clocks.tcc0_tcc1(&gclk0).unwrap();
        let mut pwm1 = Pwm1::new(tcc0_tcc1, 1.khz(), peripherals.TCC1, &mut peripherals.PM);
        pwm1.enable(Channel::_1);
        pwm1.set_period(1.khz());
        pwm1
    };

    let mut pwm2 = {
        let tcc2_tc3 = &clocks.tcc2_tc3(&gclk0).unwrap();
        let mut pwm2 = Pwm2::new(tcc2_tc3, 1.khz(), peripherals.TCC2, &mut peripherals.PM);
        pwm2.enable(Channel::_1);
        pwm2.set_period(1.khz());
        pwm2
    };

    let mut pulse_led: bsp::PlsSliderLed = pins.pls_slider_led.into();
    let mut square_led: bsp::SqSliderLed = pins.sq_slider_led.into();
    let _tri_led: bsp::TriSliderLedPwm = pins.tri_slider_led.into();

    // Enable our slider LEDs
    {
        // pulse_led.set_high().unwrap();
        // square_led.set_high().unwrap();
        // pwm1.set_duty(Channel::_1, pwm1.get_max_duty());
    }

    let mut status_ctr = 0;
    let status_thresh = 16;
    let pulse_pot_slope = 0.95f32;

    loop {
        if status_ctr == status_thresh {
            status_ctr = 0;
        }

        let mut pot_result: u16 = 0;
        let mut pitch_scaled_result: u16 = 0;
        let mut pwm_scaled_result: u16 = 0;

        cortex_m::interrupt::free(|cs| {
            let results = ADC_RESULTS.borrow(cs).borrow();
            pitch_scaled_result = results[0].clone(); // probably should have some struct that can hold the index at which i'm storing these values
            pwm_scaled_result = results[1].clone();
            pot_result = results[2].clone();
        });

        // haha jonathan you are ~banging my daughter~ wiring your pots backwards 🙃
        // dac.write_single_channel(hw::mcp4728::Channel::_1, pitch_scaled_result);
        // dac.write_single_channel(hw::mcp4728::Channel::_2, pitch_scaled_result);
        dac.write_single_channel(hw::mcp4728::Channel::_1, dac.get_max_value() - pot_result);
        dac.write_single_channel(hw::mcp4728::Channel::_2, dac.get_max_value() - pot_result);
        dac.write_single_channel(hw::mcp4728::Channel::_3, pot_result); // need to determine how to decide what source for pwm we should use

        if status_ctr == 0 {
            pwm2.set_duty(
                // Red LED on Feather
                Channel::_1,
                if pwm2.get_duty(Channel::_1) == pwm2.get_max_duty() / 4 {
                    pwm2.get_max_duty()
                } else {
                    pwm2.get_max_duty() / 4
                },
            );
        }
        pwm1.set_duty(
            // Tri Slider LED
            Channel::_1,
            pwm1.get_max_duty() as u32
                - (if pot_result > u16::pow(2, 12) - u16::pow(2, 2) {
                    pwm1.get_max_duty()
                        - if status_ctr % 2 == 0 {
                            u32::pow(2, 12)
                        } else {
                            u32::pow(2, 13)
                        }
                } else {
                    pot_result as u32 * 11
                }),
        );
        if pwm1.get_max_duty() <= (pulse_pot_slope * pot_result as f32 * 12f32).round() as u32 {
            square_led.set_high().unwrap();
        } else {
            square_led.set_low().unwrap();
        }

        status_ctr += 1;
        // cycle_delay(1024 * 1024);
    }
}

#[interrupt]
fn ADC() {
    cortex_m::interrupt::free(|cs| {
        let adc = ADC_INSTANCE.borrow(cs).borrow();
        // Is making a copy here good or bad or neutral?
        let mut results = ADC_RESULTS.borrow(cs).borrow().clone();
        // Hold as usize here since it's mostly used to slice arrays
        let mut idx: usize = IN_CTR.borrow(cs).get().into();

        // Shouldn't really be the case ever, but just in case
        if !adc.as_ref().unwrap().has_result() {
            return;
        }

        // read the current result
        let result = adc.as_ref().unwrap().read_result();
        // store single result
        results[idx] = result;
        // replace global results
        ADC_RESULTS.borrow(cs).replace(results);

        // go next, as it were
        idx = idx + 1;
        if idx == TOTAL_INS {
            idx = 0;
        }
        IN_CTR.borrow(cs).set(idx as u8); // replace

        // shift to next channel for next interrupt call;
        let channel = ADC_CHANNELS.borrow(cs).borrow().as_ref().unwrap()[idx];

        // start scanning the next result
        adc.as_ref().unwrap().scan_channel(channel);
    });
}

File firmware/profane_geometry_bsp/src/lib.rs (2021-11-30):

//! Board support crate for the Profane Geometry Eurorack Module
//! 
//! Profane geometry is an atsamd21-based open-source triangle-based quad-oscillator module, with firmware written 
//! in rust (obviously). This BSP (Board support package) is based on the work by the lovely people at [atsamd-rs](https://github.com/atsamd-rs),
//! and depends on the `atsamd-hal` HAL (hardware abstraction layer) and atsamd21g PAC (peripheral access crate). Check
//! out these packages to get some more info.
//! 
//! # How to use
//! 
//! ```
//! use profane_geometry_bsp as bsp;
//! use bsp:hal;
//! use bsp:pac;
//! 
//! // Now you have each of your bsp, hal, and pac modules available!
//! ```

#![no_std]

#[cfg(feature = "rt")]
pub use cortex_m_rt::entry;

pub use atsamd_hal as hal;
pub use hal::ehal;
pub use hal::pac;

/// Definitions related to pins and pin aliases
pub mod pins {
    use super::hal;

    hal::bsp_pins!(
        PA02 {
            /// Scaled V/Oct input        
            name: v_oct,
            aliases: {
                AlternateB: VOct
            }
        }
        PA03 {
            /// AREF pin - has 1uF capacitor to ground
            name: aref
        }
        PA04 {
            /// Scaled logic level input for the PWM cv jack
            name: pwm_cv,
            aliases: {
                AlternateB: PwmCv
            }
        }
        PA05 {
            /// Input from the pwm pot on the panel
            name: pwm_pot,
            aliases: {
                AlternateB: PwmPot
            }
        }
        PA06 {
            /// NC - named in schematic
            name: ain6
        }
        PA07 {
            /// NC - named in schematic
            name: ain7
        }
        // PA08 - PA09 NC
        PA10 {
            /// Wiper LED for the Triangle wave slider
            name: tri_slider_led,
            aliases: {
                PushPullOutput: TriSliderLed,
                AlternateF: TriSliderLedPwm
            }
        }
        PA11 {
            /// Wiper LED for the Square wave slider
            name: sq_slider_led,
            aliases: {
                PushPullOutput: SqSliderLed,
                AlternateF: SqSliderLedPwm
            }
        }
        PB10 {
            /// Wiper LED for the pulse wave slider
            name: pls_slider_led,
            aliases: {
                PushPullOutput: PlsSliderLed,
                AlternateF: PlsSliderLedPwm
            }
        }
        PB11 {
            /// Wiper LED for the notch wave slider
            name: nt_slider_led,
            aliases: {
                PushPullOutput: NtSliderLed,
                AlternateF: NtSliderLedPwm
            }
        }
        PA12 {
            /// Data pin for the I2C master used for the DAC
            name: dac_sda,
            aliases: {
                AlternateD: DacSda
            }
        }
        PA13 {
            /// Clock pin for the I2C master used for the DAC
            name: dac_scl,
            aliases: {
                AlternateD: DacScl
            }
        }
        // PA14 NC
        // PA15 NC
        PA16 {
            /// Data pin for the I2C master used for RGB LEDs on the jackboard
            name: rgb_sda,
            aliases: {
                AlternateC: RgbSda
            }
        }
        PA17 {
            /// Clock pin for the I2C master used for RGB LEDs on the jackboard
            name: rgb_scl,
            aliases: {
                AlternateC: RgbScl
            }
        }
        // PA18 NC
        // PA19 NC
        PA20 {
            /// The red shine-through power LED, PWM capable
            name: power_led,
            aliases: {
                PushPullOutput: PowerLed,
                AlternateF: PowerLedPwm
            }
        }
        // PA21 - PA23 NC
        PA24 {
            /// The D- pin for the USB connection
            name: usb_dm,
            aliases: {
                AlternateG: UsbDm
            }
        }
        PA25 {
            /// The D+ pin for the USB connection
            name: usb_dp,
            aliases: {
                AlternateG: UsbDp
            }
        }
        // PA27 - PA28 NC
        PA30 {
            /// SWCLK - Debug interface exposed via the tagconnect footprint
            name: swclk
        }
        PA31 {
            /// SWDIO - Debug interface exposed via the tagconnect footprint
            name: swdio
        }

        // PB02 - PB09 NC
        // PB10 Defined above
        // PB11 Defined above
        // PB12 - PB23 NC
    );
}

pub use pins::*;

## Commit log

2021-05-30 Sample single channel DAC write, use pulse pot as pitch input
2021-05-31 Clean up some testing code/types/errors
    [main.rs]
2021-06-03 Testing out basic Adc implementation, need to figure out interrupts
2021-06-10 ADC builder and what not, broken DynPin stuff
    [adc.rs, main.rs]
2021-06-14 Now we're cooking with interrupts
2021-11-29 update .gitignore, current kicad project
    [geo_core.sch, inputs.sch, mcu.sch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]
2021-11-30 fix old bsp reference
    [adc.rs]
2021-11-30 Cleanup and docs for profane_geometry_bsp
    BSP Changes:
    - Updated the alias for the PWM CV input from `PwmCV` to `PwmCv` so that the
    generated `DynPinId` and `DynPinMode` constants would look a bit nicer.
    - Added frontpage docs for the bsp
    - Added license info to the Cargo.toml
    Firmware Changes:
    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
2021-12-01 Debugger tooling and firmware updates
    Firmware:
    - Tweaks to the firmware to be able to reach the main event loop when
    running on the actual hardware
    - Set up clocks with the internal 32KHz oscillator, rather than a
    non-existent external oscillator.
    - Fix an off-by-one error in the ADC channel sweep logic
    - Set the red power LED high as the first thing after taking ownership
    of the peripherals singleton
    Tooling:
    - Add some basic debugging tooling/setup
    - create a .gdbinit file that connects by default to the JLink GDB
    Server
    - Configure a launch profile for vscode to enable in-editor
    debugging/breakpointing.
    [main.rs]
